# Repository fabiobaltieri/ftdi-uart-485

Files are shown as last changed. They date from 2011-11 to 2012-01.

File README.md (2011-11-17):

USB to UART/485 Interface
=========================

This project is a simple USB UART/485 interface based on the FTDI FT232
controller chip.

The board feature two LEDs for bus activity, a 2x3 2.54mm strip with TTL UART
signals and a 485 transceiver with a 8P8C connettor compatible with both
generic 8P8C connectors and Neutrik Ethercon connectors.

License
-------

This program is free software: you can redistribute it and/or modify
it under the terms of the GNU General Public License as published by
the Free Software Foundation, either version 3 of the License, or
(at your option) any later version.

Contents
--------

    COPYING     text version of the GPL
    README      this file
    hardware/   source directory for the hardware design files

Firmware
--------

No firmware is needed for this design. FTDI drivers are already available on
most GNU/Linux distributions.

Hardware
--------

All hardware files (schematic, layout and libraries) are in CadSoft Eagle
format.

The PCB is designed to work at 3.3V for UART signal/485 levels, but can be
easily modified to work at 5V by bypassing the 3.3V linear regulator and
mounting a standard 5V 485 transceiver.

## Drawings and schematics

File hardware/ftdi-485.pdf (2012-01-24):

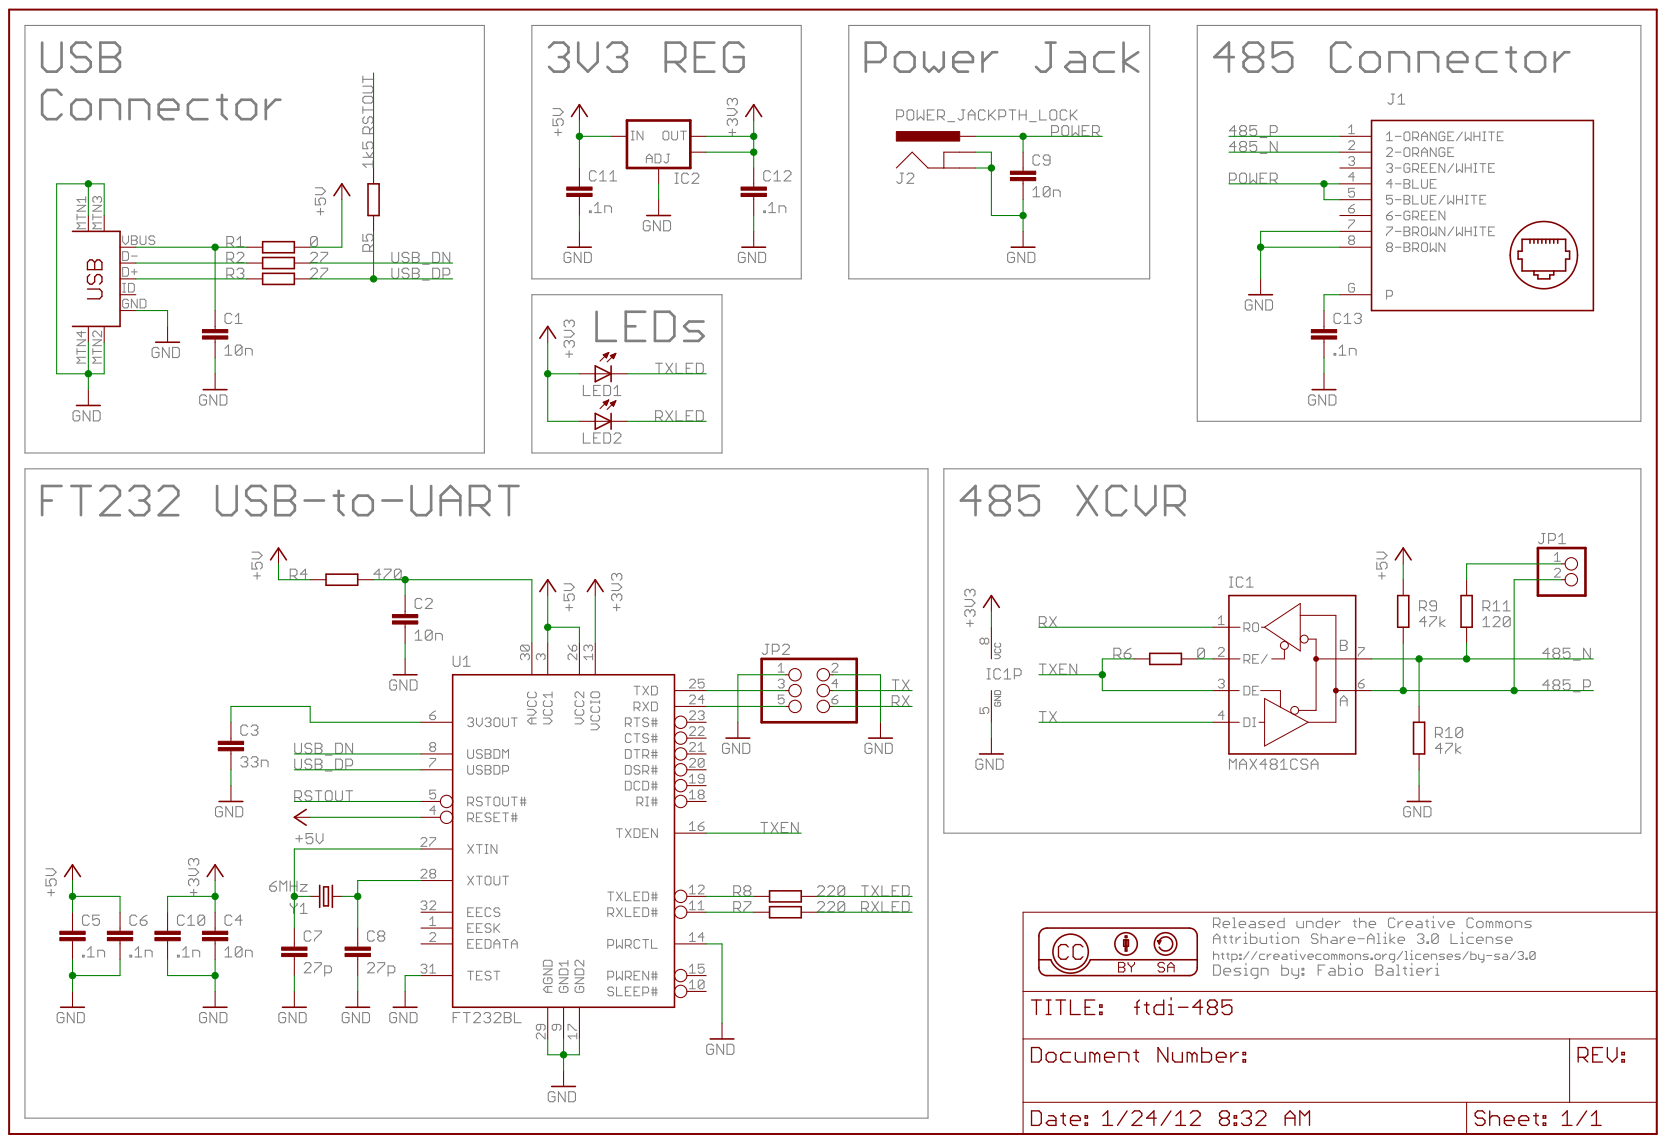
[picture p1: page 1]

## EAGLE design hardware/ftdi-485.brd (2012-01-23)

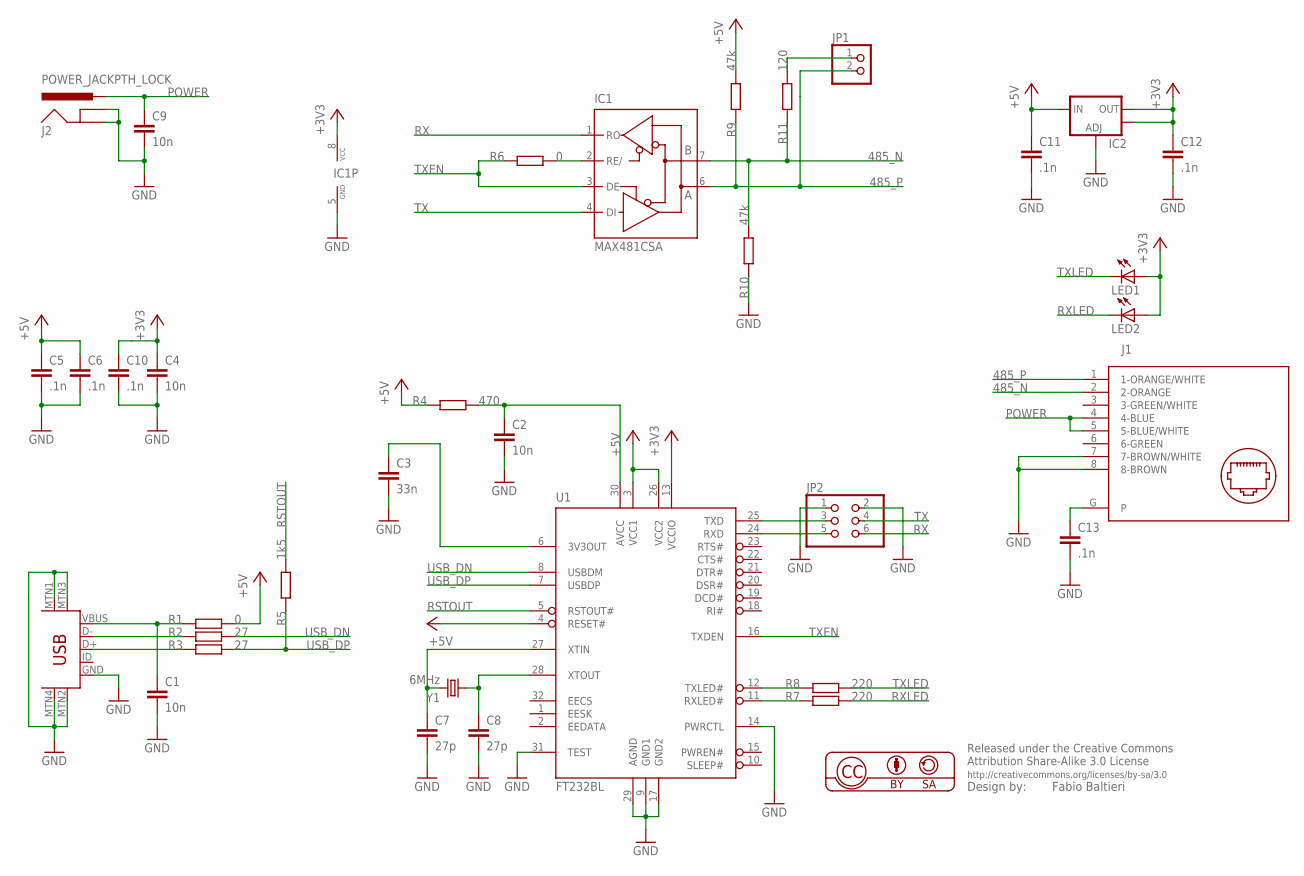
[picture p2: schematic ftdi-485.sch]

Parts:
C1, C2, C4, C9: 10n; C0805
C3: 33n; C0805
C5, C6, C10, C11, C12, C13: .1n; C0805
C7, C8: 27p; C0805
IC1: MAX481CSA; SO08
IC2: V_REG_LM1117SOT223; SOT223
J1: NE8FAH
J2: POWER_JACKPTH_LOCK; POWER_JACK_PTH_LOCK
JP1: PINHD-1X2; 1X02
JP2: PINHD-2X3; 2X03
LED1, LED2: LEDCHIP-LED0805; CHIP-LED0805
R1, R6: 0; R0603
R2, R3: 27; R0603
R4: 470; R0603
R5: 1k5; R0603
R7, R8: 220; R0603
R9, R10: 47k; R0603
R11: 120; R0603
U1: FT232BL; LQFP32
U$2: USB-MINIB-5PIN; USB-MINIB
Y1: 6MHz; HC49U-V

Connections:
485_N: IC1.7 (B), J1.2 (2-ORANGE), R10.2, R11.1
485_P: IC1.6 (A), J1.1 (1-ORANGE/WHITE), JP1.2, R9.1
+3V3: C4.1, C10.1, C12.1, IC1.8 (VCC), IC2.2 (OUT), IC2.4 (OUT), LED1.A, LED2.A, U1.13 (VCCIO)
+5V: C5.1, C6.1, C11.1, IC2.3 (IN), R1.2, R4.1, R9.2, U1.3 (VCC1), U1.4 (RESET#), U1.26 (VCC2)
GND: C1.2, C2.2, C3.2, C4.2, C5.2, C6.2, C7.2, C8.2, C9.2, C10.2, C11.2, C12.2, C13.2, IC1.5 (GND), IC2.1 (ADJ), J1.7 (7-BROWN/WHITE), J1.8 (8-BROWN), J2.GND, J2.GNDBREAK, JP2.1, JP2.2, R10.1, U1.9 (GND1), U1.14 (PWRCTL), U1.17 (GND2), U1.29 (AGND), U1.31 (TEST), U$2.GND, U$2.MTN1 (MTN2), U$2.MTN2 (MTN3), U$2.MTN3 (MTN1), U$2.MTN4
unnamed: C1.1, R1.1, U$2.VBUS
unnamed: R2.1, U$2.D-
unnamed: R3.1, U$2.D+
unnamed: R8.1, U1.12 (TXLED#)
unnamed: C2.1, R4.2, U1.30 (AVCC)
unnamed: C3.1, U1.6 (3V3OUT)
unnamed: C7.1, U1.27 (XTIN), Y1.2
unnamed: C8.1, U1.28 (XTOUT), Y1.1
unnamed: R7.1, U1.11 (RXLED#)
unnamed: IC1.2 (RE/), R6.2
unnamed: JP1.1, R11.2
unnamed: JP2.5, U1.24 (RXD)
unnamed: JP2.3, U1.25 (TXD)
unnamed: C13.1, J1.G
POWER: C9.1, J1.4 (4-BLUE), J1.5 (5-BLUE/WHITE), J2.PWR
RSTOUT: R5.2, U1.5 (RSTOUT#)
RX: IC1.1 (RO), JP2.6
RXLED: LED2.C, R7.2
TX: IC1.4 (DI), JP2.4
TXEN: IC1.3 (DE), R6.1, U1.16 (TXDEN)
TXLED: LED1.C, R8.2
USB_DN: R2.2, U1.8 (USBDM)
USB_DP: R3.2, R5.1, U1.7 (USBDP)

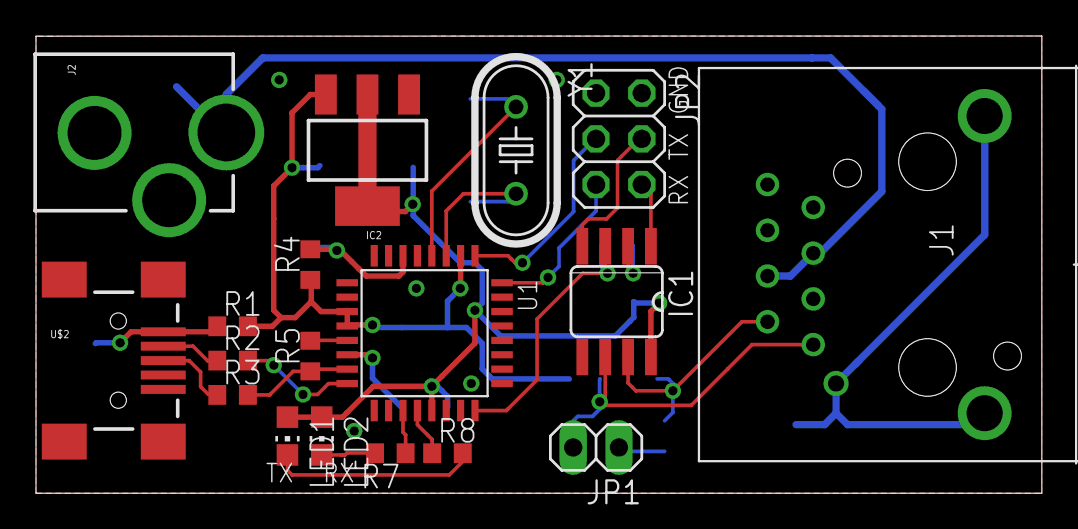
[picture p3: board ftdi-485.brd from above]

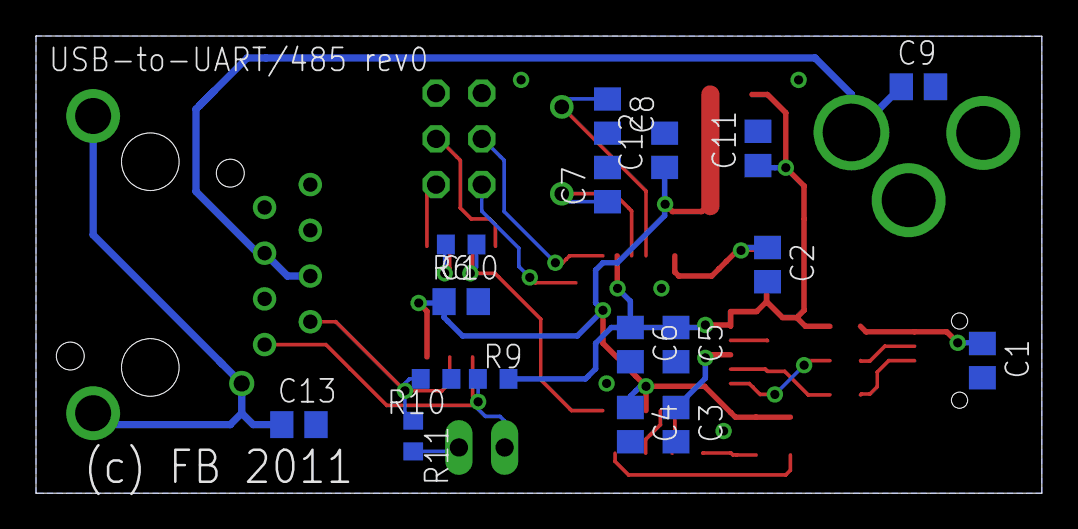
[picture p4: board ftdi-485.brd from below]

Board: 2 copper layers, 55.9 x 25.4 mm, 35 parts (17 on the bottom side), 28 nets.

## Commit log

2011-11-17 initial import of hardware files
    [ftdi-485.brd, ftdi-485.sch]
2011-11-17 hardware: add schematic in pdf version
2011-11-20 hardware: add CC BY-SA license
    [ftdi-485.brd, ftdi-485.sch]
2012-01-23 hardware: convert files to eagle v6 version (xml)
    [ftdi-485.brd, ftdi-485.sch]
2012-01-24 hardware: cosmetic changes
    [ftdi-485.sch]

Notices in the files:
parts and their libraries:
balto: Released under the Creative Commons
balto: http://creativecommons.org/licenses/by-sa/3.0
